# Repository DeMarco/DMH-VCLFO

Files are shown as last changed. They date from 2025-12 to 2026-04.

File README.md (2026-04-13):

# DMH-VCLFO
Kosmo format Voltage Controlled tripple LFO module

## Features
6 waveforms, all +5V/-5V
  - Square
  - Saw
  - Ramp
  - Random
  - Sine
  - Triangle

3 frequency ranges
  - Fast
  - Super Fast (Audio rate!)
  - Slow

Hard Sync input

Can also do VCO duties!

Excellent V/Oct trackig over 5 octaves

CV Amount knob serves as Fine Frequency Adjustment when no cable is connected to CV input

Adjustable range for Fine knob

## Current consumption:
+12V --> 65mA

-12V --> 60mA

## Dimensions
Height: 20cm

Width: 10cm

Depth: 10cm

## PCB set
- Panel
- Controls
- Main
- Submodule (x3)

Final Gerbers available in "Gerbers" folder

## Single VCLFO version
The KiCad project named "Single Unit" contains the circuit for one VCLFO in a single page schematic without any inter-PCB connectors. This can be useful if anyone is interested in designing their own PCBs or entire modules in non-Kosmo dimensions.

## Font
For viewing/customizing in KiCad, I recommend downloading and installing the Nulshock font from Typodermic: https://typodermicfonts.com/nulshock/




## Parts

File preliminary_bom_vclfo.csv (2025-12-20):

Reference | Value | Datasheet | Footprint | Qty | DNP
C1,C2 | 47uF | ~ | Capacitor_THT:CP_Radial_D5.0mm_P2.00mm | 2
C3 | 10nF | ~ | Capacitor_THT:C_Disc_D4.3mm_W1.9mm_P5.00mm | 1
C4,C6 | 1uF | ~ | Capacitor_THT:C_Disc_D4.3mm_W1.9mm_P5.00mm | 2
C5 | 1nF | ~ | Capacitor_THT:C_Disc_D4.3mm_W1.9mm_P5.00mm | 1
C7,C8 | 100nF | ~ | Capacitor_THT:C_Disc_D4.3mm_W1.9mm_P5.00mm | 2
C9,C10,C11 | 100pF | ~ | Capacitor_THT:C_Disc_D4.3mm_W1.9mm_P5.00mm | 3
D1,D2 | SB140 | http://www.diodes.com/_files/datasheets/ds23022.pdf | Diode_THT:D_DO-41_SOD81_P10.16mm_Horizontal | 2
D3,D4 | LM4040LP-5 | http://www.ti.com/lit/ds/symlink/lm4040-n.pdf | Package_TO_SOT_THT:TO-92_Inline | 2
D5 | LED_Red | ~ | LED_THT:LED_D3.0mm | 1
D6 | LED_Yellow | ~ | LED_THT:LED_D3.0mm | 1
D7,D8,D9,D10,D11,D12,D13,D14,D15,D16,D17 | 1N4148 | https://assets.nexperia.com/documents/data-sheet/1N4148_1N4448.pdf,~ | Diode_THT:D_DO-35_SOD27_P7.62mm_Horizontal | 11
J1,J2,J3,J4,J5,J6 | TS_Jack_6.35mm_Sw | ~ | SynthStuff:CUI_MJ-63052A | 6
J10 | IDC_02x05 | ~ | SynthStuff:IDC-Header_2x05_P2.54mm_Vertical_BackBone | 1
J100 | IDC_02x05 | ~ | SynthStuff:IDC-Header_2x05_P2.54mm_Vertical_Eurorack | 1
Q1,Q3,Q7 | BC548 | https://www.onsemi.com/pub/Collateral/BC550-D.pdf | Package_TO_SOT_THT:TO-92L_Inline_Wide | 3
Q2 | BC558 | https://www.onsemi.com/pub/Collateral/BC556BTA-D.pdf | Package_TO_SOT_THT:TO-92L_Inline_Wide | 1
Q4 | BC548 | https://www.onsemi.com/pub/Collateral/BC550-D.pdf | Package_TO_SOT_THT:TO-92_Inline_Wide | 1
Q5 | BS170 | https://www.onsemi.com/pub/Collateral/BS170-D.PDF | Package_TO_SOT_THT:TO-92_Inline | 1
Q6 | J113 | https://www.onsemi.com/pub/Collateral/MMBFJ113-D.PDF | Package_TO_SOT_THT:TO-92L_Inline | 1
R1,R2 | 6k8 | ~ | Resistor_THT:R_Axial_DIN0207_L6.3mm_D2.5mm_P7.62mm_Horizontal | 2
R3 | 270R | ~ | Resistor_THT:R_Axial_DIN0207_L6.3mm_D2.5mm_P7.62mm_Horizontal | 1
R4,R57 | 33k | ~ | Resistor_THT:R_Axial_DIN0207_L6.3mm_D2.5mm_P7.62mm_Horizontal | 2
R5,R6,R7,R8,R9,R10,R11,R12,R13,R14,R15,R16,R17,R18,R19,R20,R21,R22,R23,R24,R25,R26,R27,R28,R37,R38,R39,R40,R43,R45,R47,R50,R55,R58,R60,R64,R65,R68,R72,R73,R78,R79,R82,R86 | 100k | ~ | Resistor_THT:R_Axial_DIN0207_L6.3mm_D2.5mm_P7.62mm_Horizontal | 44
R29,R30,R31,R32,R33,R34,R44,R63,R70,R83 | 1k | ~ | Resistor_THT:R_Axial_DIN0207_L6.3mm_D2.5mm_P7.62mm_Horizontal | 10
R35,R36,R51,R53,R56,R59,R74,R75,R77,R80 | 10k | ~ | Resistor_THT:R_Axial_DIN0207_L6.3mm_D2.5mm_P7.62mm_Horizontal | 10
R41,R42 | 3k3 | ~ | Resistor_THT:R_Axial_DIN0207_L6.3mm_D2.5mm_P7.62mm_Horizontal | 2
R46,R48,R49 | 51k | ~ | Resistor_THT:R_Axial_DIN0207_L6.3mm_D2.5mm_P7.62mm_Horizontal | 3
R52 | 3k9 | ~ | Resistor_THT:R_Axial_DIN0207_L6.3mm_D2.5mm_P7.62mm_Horizontal | 1
R54 | 330R | ~ | Resistor_THT:R_Axial_DIN0207_L6.3mm_D2.5mm_P7.62mm_Horizontal | 1
R61,R81 | 1M | ~ | Resistor_THT:R_Axial_DIN0207_L6.3mm_D2.5mm_P7.62mm_Horizontal | 2
R62 | 47k | ~ | Resistor_THT:R_Axial_DIN0207_L6.3mm_D2.5mm_P7.62mm_Horizontal | 1
R66,R67,R85 | 22k | ~ | Resistor_THT:R_Axial_DIN0207_L6.3mm_D2.5mm_P7.62mm_Horizontal | 3
R69,R71 | 560 | ~ | Resistor_THT:R_Axial_DIN0207_L6.3mm_D2.5mm_P7.62mm_Horizontal | 2
R76 | 82k | ~ | Resistor_THT:R_Axial_DIN0207_L6.3mm_D2.5mm_P7.62mm_Horizontal | 1
RV1,RV2 | B100k | ~ | SynthStuff:Potentiometer_TT_P110KH1 | 2
RV3 | 50k | ~ | Potentiometer_THT:Potentiometer_Bourns_3296X_Horizontal | 1
RV4 | 10k | ~ | Potentiometer_THT:Potentiometer_Bourns_3296W_Vertical | 1
SW1,SW3,SW4 | SW_SPDT | ~ | SynthStuff:Toggle_Switch_TE | 3
SW2 | SPDT_OnOffOn | ~ | SynthStuff:Toggle_Switch_TE | 1
U1,U2,U10,U11,U12 | TL074 | http://www.ti.com/lit/ds/symlink/tl071.pdf | Package_DIP:DIP-14_W7.62mm_Socket | 5

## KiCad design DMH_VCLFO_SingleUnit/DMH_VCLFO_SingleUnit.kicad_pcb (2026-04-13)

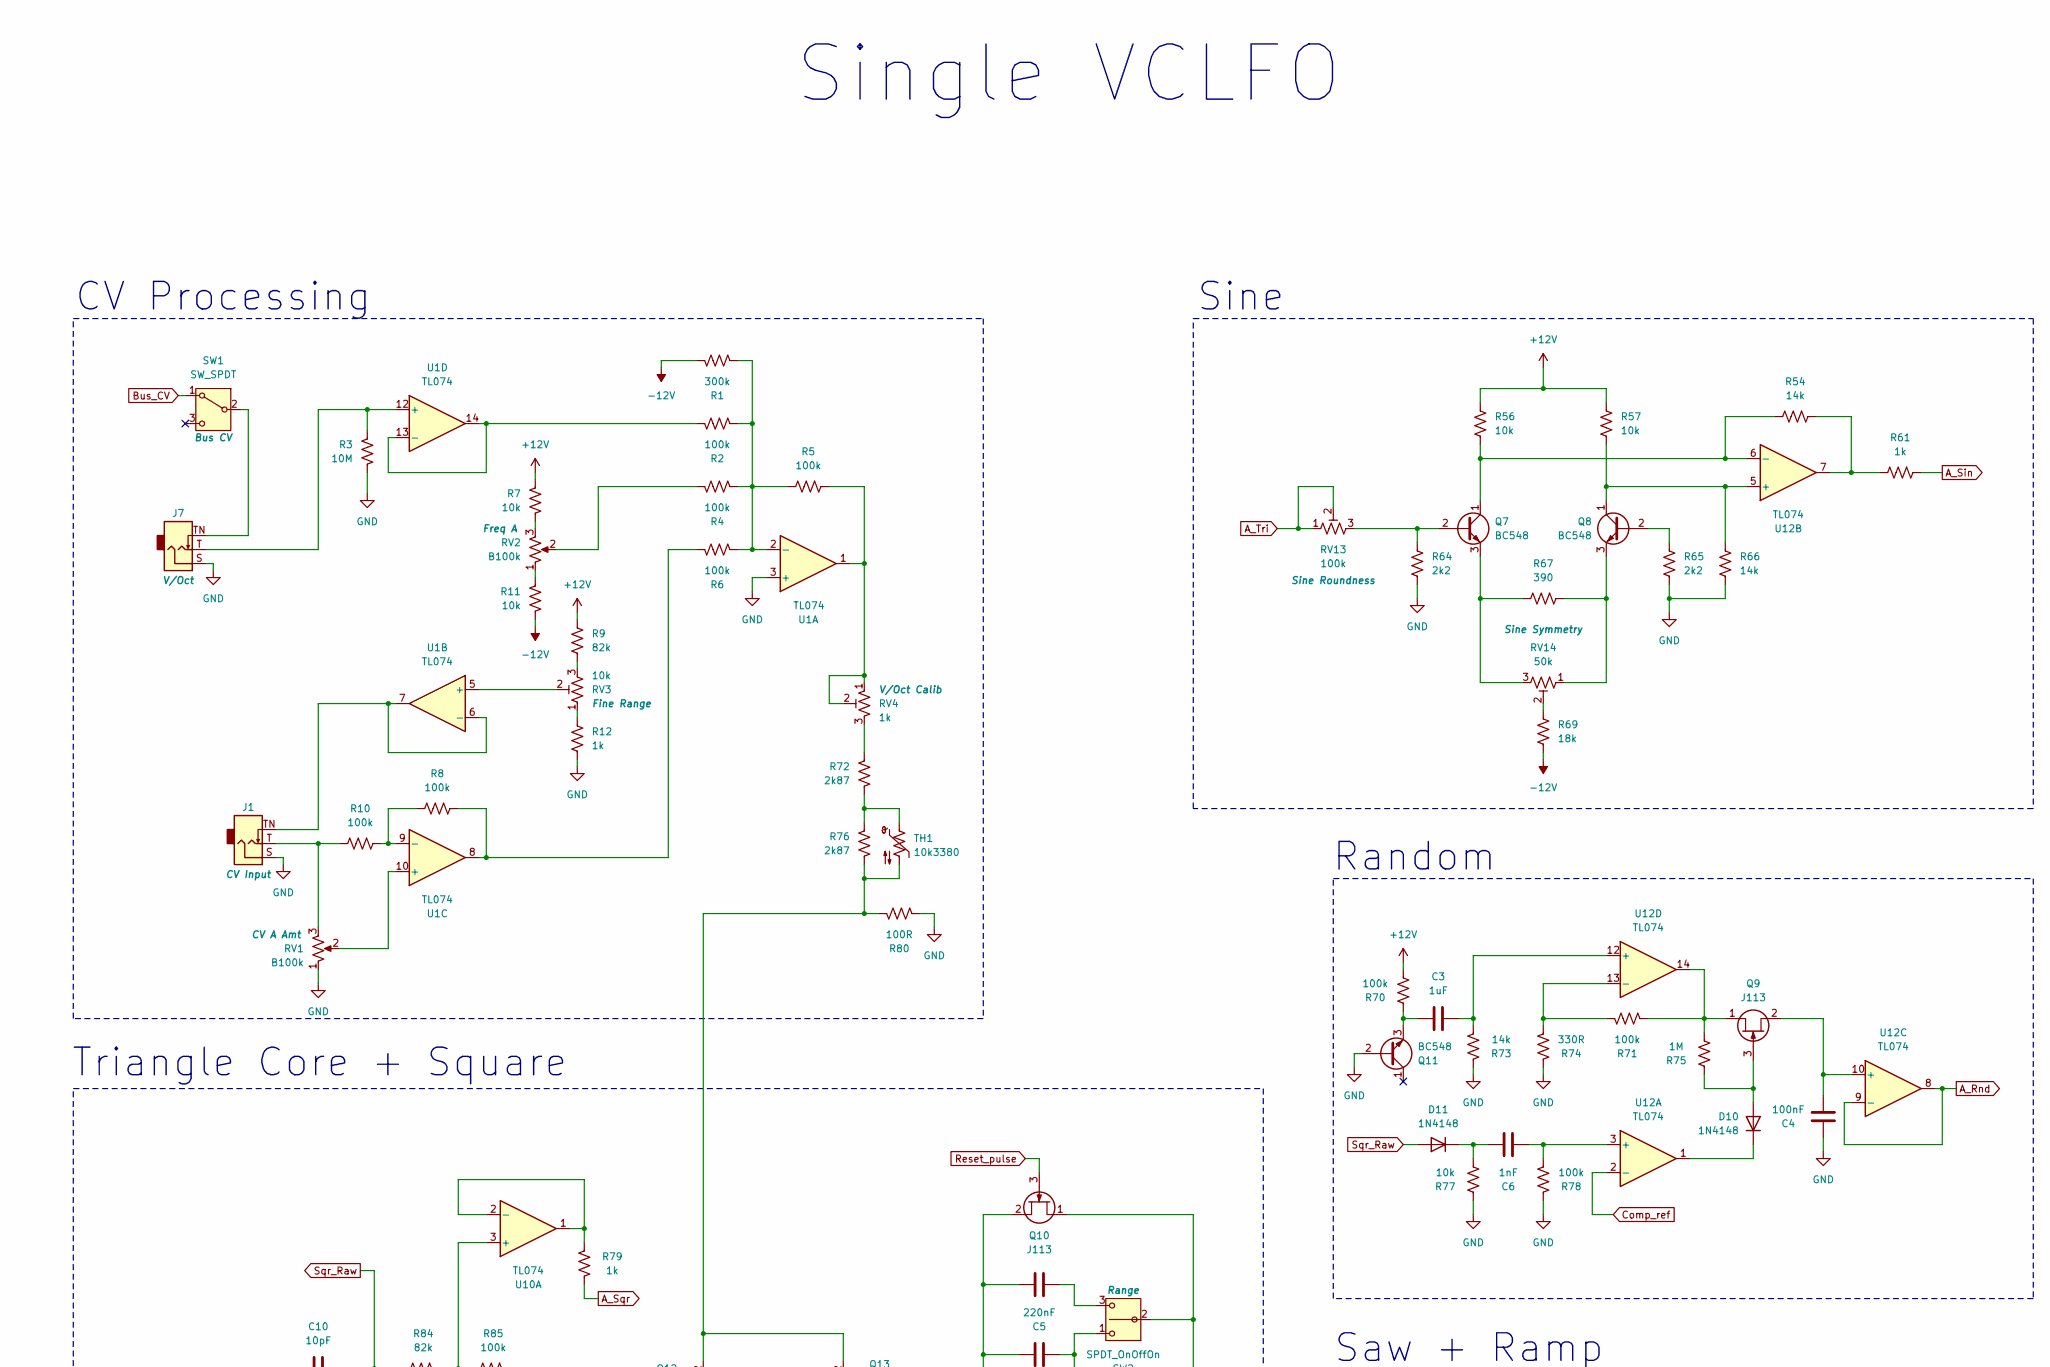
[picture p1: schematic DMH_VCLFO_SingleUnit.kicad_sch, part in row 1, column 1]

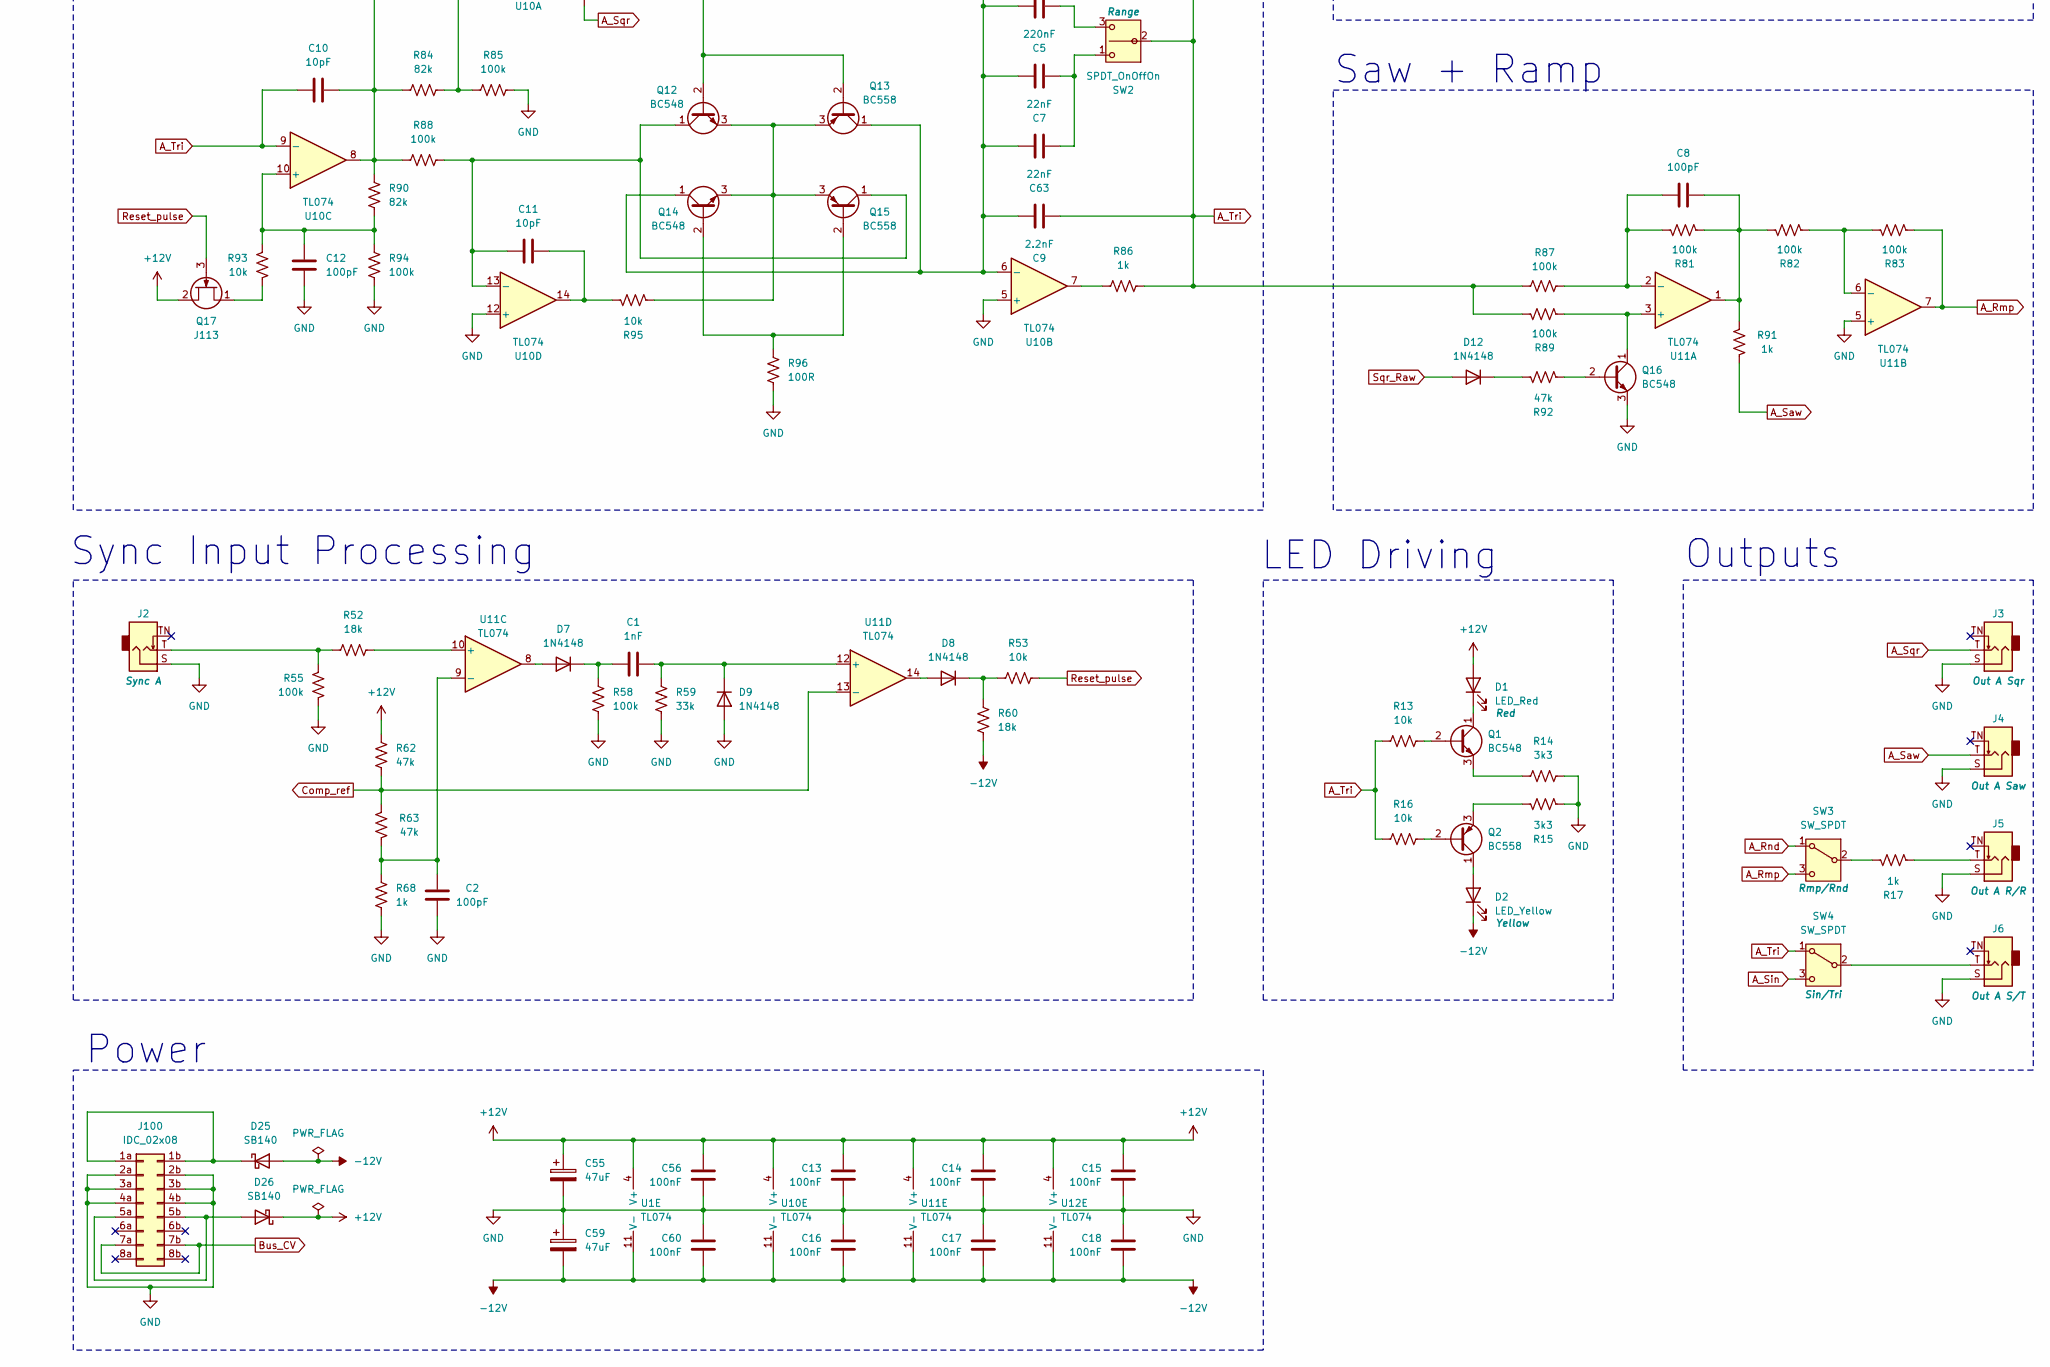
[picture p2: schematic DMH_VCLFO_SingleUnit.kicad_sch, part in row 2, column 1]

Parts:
C1, C6: 1nF; C_Disc_D4.3mm_W1.9mm_P5.00mm
C2, C8, C12: 100pF; C_Disc_D3.0mm_W2.0mm_P2.50mm
C3: 1uF; C_Disc_D4.3mm_W1.9mm_P5.00mm
C4, C13, C14, C15, C16, C17, C18, C56, C60: 100nF; C_Disc_D4.3mm_W1.9mm_P5.00mm
C5: 220nF; C_Disc_D4.3mm_W1.9mm_P5.00mm
C7, C63: 22nF; C_Disc_D4.3mm_W1.9mm_P5.00mm
C9: 2.2nF; C_Disc_D3.0mm_W2.0mm_P2.50mm
C10, C11: 10pF; C_Disc_D3.0mm_W2.0mm_P2.50mm
C55, C59: 47uF; CP_Radial_D5.0mm_P2.00mm
D1: LED_Red; LED_D3.0mm
D2: LED_Yellow; LED_D3.0mm
D7, D8, D9, D10, D11, D12: 1N4148; D_DO-35_SOD27_P7.62mm_Horizontal
D25, D26: SB140; D_DO-41_SOD81_P10.16mm_Horizontal
J1, J2, J3, J4, J5, J6, J7: TS_Jack_6.35mm_Sw; CUI_MJ-63052A
J100: IDC_02x08; IDC-Header_2x08_P2.54mm_Vertical_Eurorack
Q1, Q7, Q8, Q11, Q12, Q14, Q16: BC548; TO-92L_Inline_Wide
Q2, Q13, Q15: BC558; TO-92L_Inline_Wide
Q9, Q10, Q17: J113; TO-92L_Inline
R1: 300k; R_Axial_DIN0207_L6.3mm_D2.5mm_P7.62mm_Horizontal
R2, R4, R5, R6, R8, R10, R55, R58, R70, R71, R78, R81, R82, R83, R85, R87, R88, R89, R94: 100k; R_Axial_DIN0207_L6.3mm_D2.5mm_P7.62mm_Horizontal
R3: 10M; R_Axial_DIN0207_L6.3mm_D2.5mm_P7.62mm_Horizontal
R7, R11, R13, R16, R53, R56, R57, R77, R93, R95: 10k; R_Axial_DIN0207_L6.3mm_D2.5mm_P7.62mm_Horizontal
R9, R84, R90: 82k; R_Axial_DIN0207_L6.3mm_D2.5mm_P7.62mm_Horizontal
R12, R17, R61, R68, R79, R86, R91: 1k; R_Axial_DIN0207_L6.3mm_D2.5mm_P7.62mm_Horizontal
R14, R15: 3k3; R_Axial_DIN0207_L6.3mm_D2.5mm_P7.62mm_Horizontal
R52, R60, R69: 18k; R_Axial_DIN0207_L6.3mm_D2.5mm_P7.62mm_Horizontal
R54, R66, R73: 14k; R_Axial_DIN0207_L6.3mm_D2.5mm_P7.62mm_Horizontal
R59: 33k; R_Axial_DIN0207_L6.3mm_D2.5mm_P7.62mm_Horizontal
R62, R63, R92: 47k; R_Axial_DIN0207_L6.3mm_D2.5mm_P7.62mm_Horizontal
R64, R65: 2k2; R_Axial_DIN0207_L6.3mm_D2.5mm_P7.62mm_Horizontal
R67: 390; R_Axial_DIN0207_L6.3mm_D2.5mm_P7.62mm_Horizontal
R72, R76: 2k87; R_Axial_DIN0207_L6.3mm_D2.5mm_P7.62mm_Horizontal
R74: 330R; R_Axial_DIN0207_L6.3mm_D2.5mm_P7.62mm_Horizontal
R75: 1M; R_Axial_DIN0207_L6.3mm_D2.5mm_P7.62mm_Horizontal
R80, R96: 100R; R_Axial_DIN0207_L6.3mm_D2.5mm_P7.62mm_Horizontal
RV1, RV2: B100k; Potentiometer_Alpha_RD901F-40-00D_Single_Vertical
RV3: 10k; Potentiometer_Bourns_3296W_Vertical
RV4: 1k; Potentiometer_Bourns_3296W_Vertical
RV13: 100k; Potentiometer_Bourns_3296W_Vertical
RV14: 50k; Potentiometer_Bourns_3296W_Vertical
SW1, SW3, SW4: SW_SPDT; Toggle_Switch_TE
SW2: SPDT_OnOffOn; Toggle_Switch_TE
TH1: 10k3380; R_Axial_DIN0204_L3.6mm_D1.6mm_P1.90mm_Vertical
U1, U10, U11, U12: TL074; DIP-14_W7.62mm_Socket

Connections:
+12V: C13.1, C14.1, C15.1, C55.1, C56.1, D1.2 (A), D26.1 (K), Q17.2 (S), R7.1, R9.2, R56.1, R57.1, R62.1, R70.1, U1.4 (V+), U10.4 (V+), U11.4 (V+), U12.4 (V+)
-12V: C16.2, C17.2, C18.2, C59.2, C60.2, D2.1 (K), D25.2 (A), R1.1, R11.2, R60.2, R69.1, U1.11 (V-), U10.11 (V-), U11.11 (V-), U12.11 (V-)
A_Rmp: R83.2, SW3.3 (C), U11.7
A_Rnd: SW3.1 (A), U12.8, U12.9 (-)
A_Saw: J4.T, R91.1
A_Sin: R61.2, SW4.3 (C)
A_Sqr: J3.T, R79.1
A_Tri: C9.2, C10.1, Q10.1 (D), R13.1, R16.1, R86.1, R87.1, R89.1, RV13.1, RV13.2, SW2.2 (B), SW4.1 (A), U10.9 (-)
Bus_CV: J100.7a, J100.7b, SW1.1 (A)
Comp_ref: R62.2, R63.1, U11.13 (-), U12.2 (-)
GND: C2.1, C4.2, C12.1, C13.2, C14.2, C15.2, C16.1, C17.1, C18.1, C55.2, C56.2, C59.1, C60.1, D9.2 (A), J1.S, J2.S, J3.S, J4.S, J5.S, J6.S, J7.S, J100.2a, J100.2b, J100.3a, J100.3b, J100.4a, J100.4b, Q11.2 (B), Q16.3 (E), R3.2, R12.1, R14.2, R15.2, R55.1, R58.2, R59.2, R64.2, R65.2, R66.2, R68.2, R73.2, R74.2, R77.2, R78.2, R80.1, R85.1, R94.2, R96.2, RV1.1, U1.3 (+), U10.5 (+), U10.12 (+), U11.5 (+)
unnamed: C8.2, R81.2, R82.1, R91.2, U11.1
unnamed: C11.2, R95.2, U10.14
unnamed: D1.1 (K), Q1.1 (C)
unnamed: D2.2 (A), Q2.1 (C)
unnamed: D7.2 (A), U11.8
unnamed: C1.1, D7.1 (K), R58.1
unnamed: D8.2 (A), U11.14
unnamed: D8.1 (K), R53.2, R60.1
unnamed: C1.2, D9.1 (K), R59.1, U11.12 (+)
unnamed: D10.2 (A), Q9.3 (G), R75.2
unnamed: D10.1 (K), U12.1
unnamed: C6.2, D11.1 (K), R77.1
unnamed: D12.1 (K), R92.1
unnamed: D25.1 (K), J100.1a, J100.1b
unnamed: D26.2 (A), J100.5a, J100.5b
unnamed: J1.T, R10.1, RV1.3
unnamed: J2.T, R52.1, R55.2
unnamed: J5.T, R17.2
unnamed: Q1.2 (B), R13.2
unnamed: Q1.3 (E), R14.1
unnamed: Q2.2 (B), R16.2
unnamed: Q2.3 (E), R15.1
unnamed: Q7.2 (B), R64.1, RV13.3
unnamed: Q7.1 (C), R54.1, R56.2, U12.6 (-)
unnamed: Q7.3 (E), R67.1, RV14.3
unnamed: Q8.2 (B), R65.1
unnamed: Q8.1 (C), R57.2, R66.1, U12.5 (+)
unnamed: Q8.3 (E), R67.2, RV14.1
unnamed: Q9.1 (D), R71.1, R75.1, U12.14
unnamed: C4.1, Q9.2 (S), U12.10 (+)
unnamed: C5.1, C7.1, C9.1, C63.1, Q10.2 (S), Q13.1 (C), Q14.1 (C), U10.6 (-)
unnamed: C3.1, Q11.3 (E), R70.2
unnamed: Q12.2 (B), Q13.2 (B), R76.2, R80.2, TH1.2
unnamed: C11.1, Q12.1 (C), Q15.1 (C), R88.1, U10.13 (-)
unnamed: Q12.3 (E), Q13.3 (E), Q14.3 (E), Q15.3 (E), R95.1
unnamed: Q14.2 (B), Q15.2 (B), R96.1
unnamed: Q16.2 (B), R92.2
unnamed: Q16.1 (C), R89.2, U11.3 (+)
unnamed: Q17.1 (D), R93.2
unnamed: R4.2, RV2.2
unnamed: R5.2, RV4.1, RV4.2, U1.1
unnamed: R6.2, R8.2, U1.8
unnamed: R7.2, RV2.3
unnamed: R9.1, RV3.3
unnamed: R11.1, RV2.1
unnamed: R12.2, RV3.1
unnamed: R54.2, R61.1, U12.7
unnamed: R69.2, RV14.2
unnamed: R72.1, RV4.3
unnamed: R72.2, R76.1, TH1.1
unnamed: R86.2, U10.7
unnamed: J7.TN, SW1.2 (B)
unnamed: C7.2, C63.2, SW2.1 (A)
unnamed: C5.2, SW2.3 (C)
unnamed: R17.1, SW3.2 (B)
unnamed: J6.T, SW4.2 (B)
unnamed: R1.2, R2.1, R4.1, R5.1, R6.1, U1.2 (-)
unnamed: RV3.2, U1.5 (+)
unnamed: J1.TN, U1.6 (-), U1.7
unnamed: RV1.2, U1.10 (+)
unnamed: R8.1, R10.2, U1.9 (-)
unnamed: J7.T, R3.1, U1.12 (+)
unnamed: R2.2, U1.13 (-), U1.14
unnamed: R84.1, R85.2, U10.3 (+)
unnamed: R79.2, U10.1, U10.2 (-)
unnamed: C12.2, R90.2, R93.1, R94.1, U10.10 (+)
unnamed: C8.1, R81.1, R87.2, U11.2 (-)
unnamed: R82.2, R83.1, U11.6 (-)
unnamed: R52.2, U11.10 (+)
unnamed: C2.2, R63.2, R68.1, U11.9 (-)
unnamed: C6.1, R78.1, U12.3 (+)
unnamed: C3.2, R73.1, U12.12 (+)
unnamed: R71.2, R74.1, U12.13 (-)
Reset_pulse: Q10.3 (G), Q17.3 (G), R53.1
Sqr_Raw: C10.2, D11.2 (A), D12.2 (A), R84.2, R88.2, R90.1, U10.8

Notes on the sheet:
Random
Triangle Core + Square
Sine
CV Processing
Single VCLFO
Outputs
Power
Saw + Ramp
LED Driving
Sync Input Processing

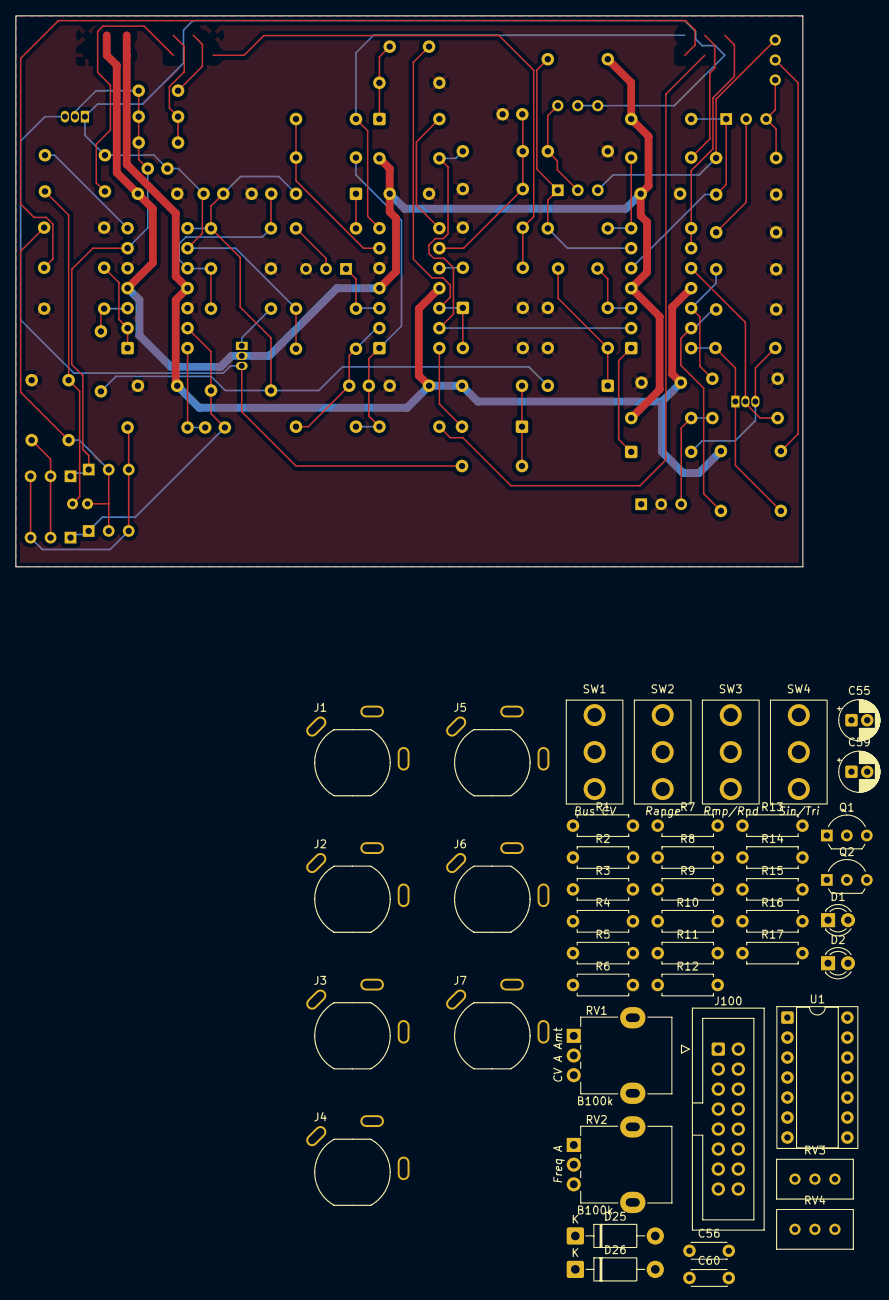
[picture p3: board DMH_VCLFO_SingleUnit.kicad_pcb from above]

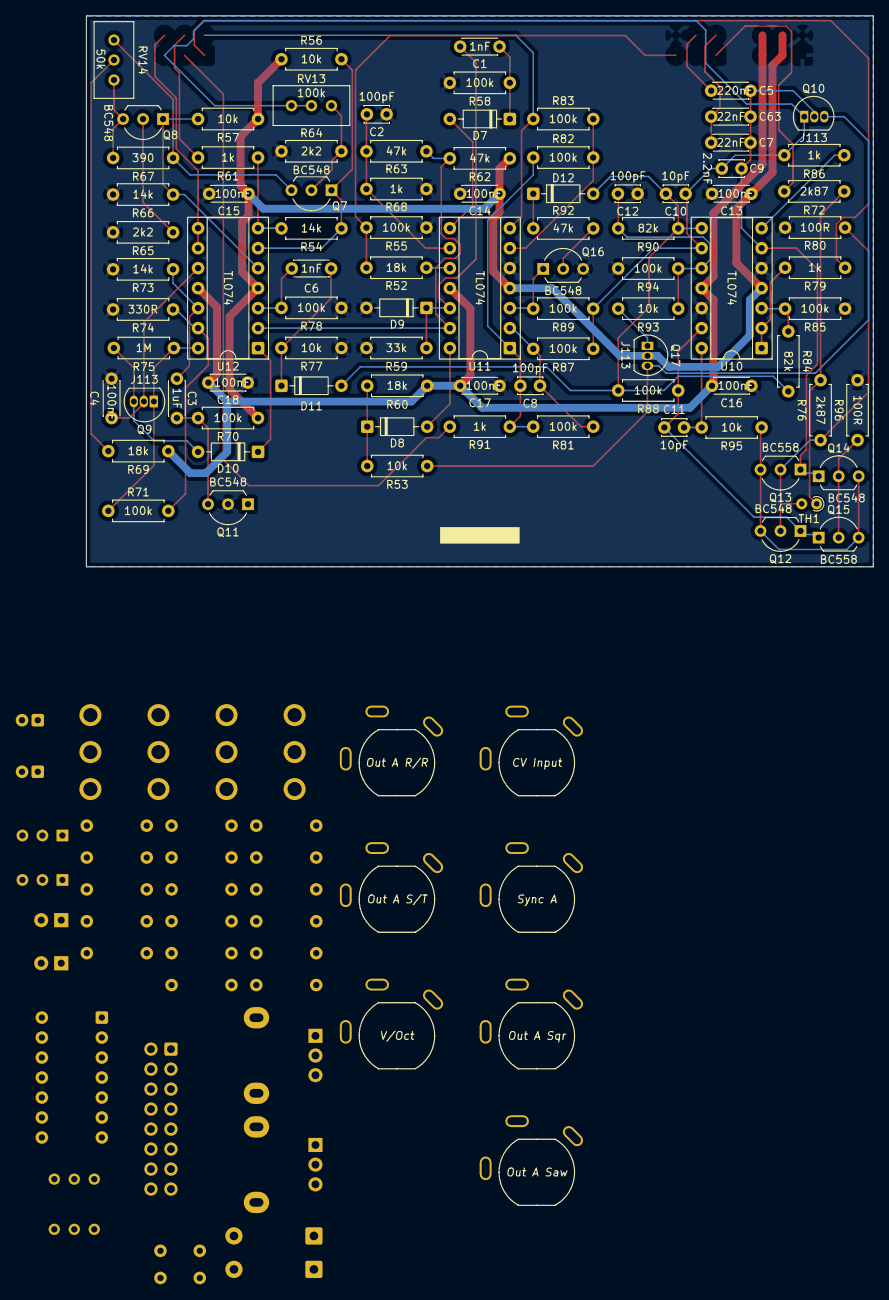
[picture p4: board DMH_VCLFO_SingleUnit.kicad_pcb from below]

Board: 2 copper layers, 100.0 x 70.0 mm, 131 parts (87 on the bottom side), 86 nets.

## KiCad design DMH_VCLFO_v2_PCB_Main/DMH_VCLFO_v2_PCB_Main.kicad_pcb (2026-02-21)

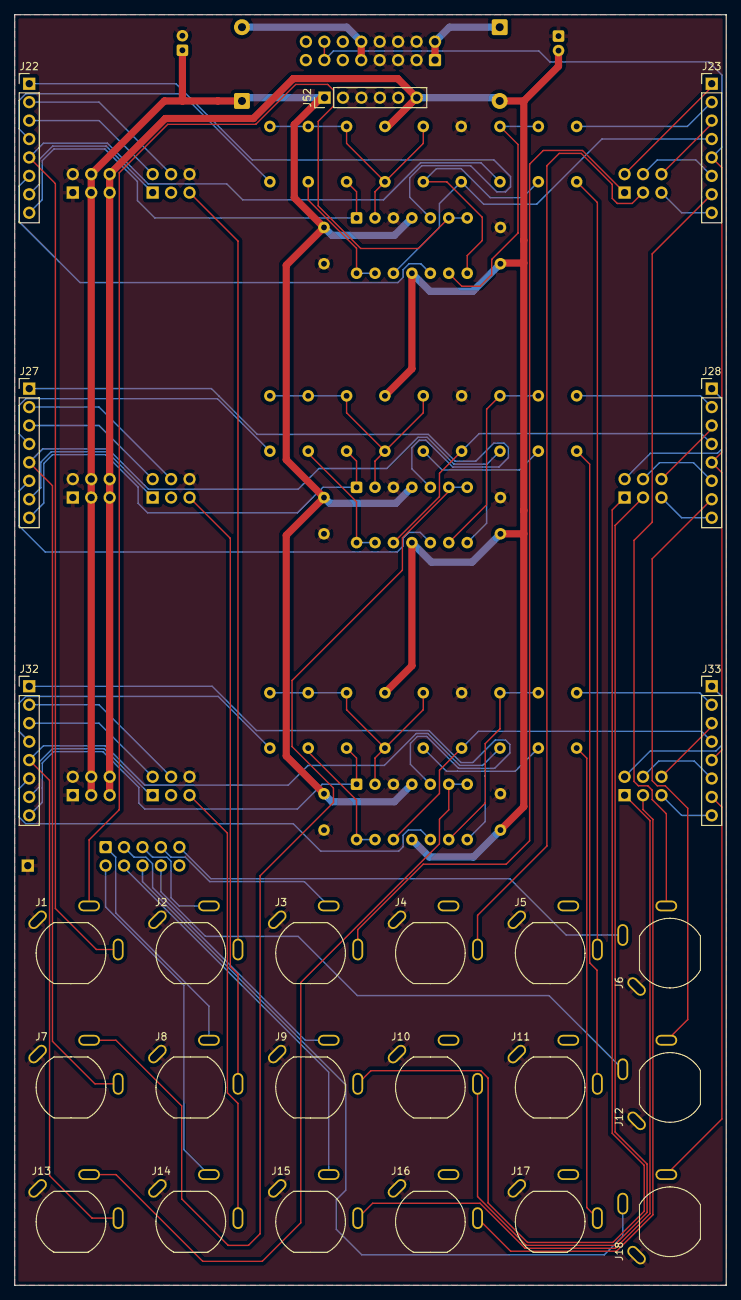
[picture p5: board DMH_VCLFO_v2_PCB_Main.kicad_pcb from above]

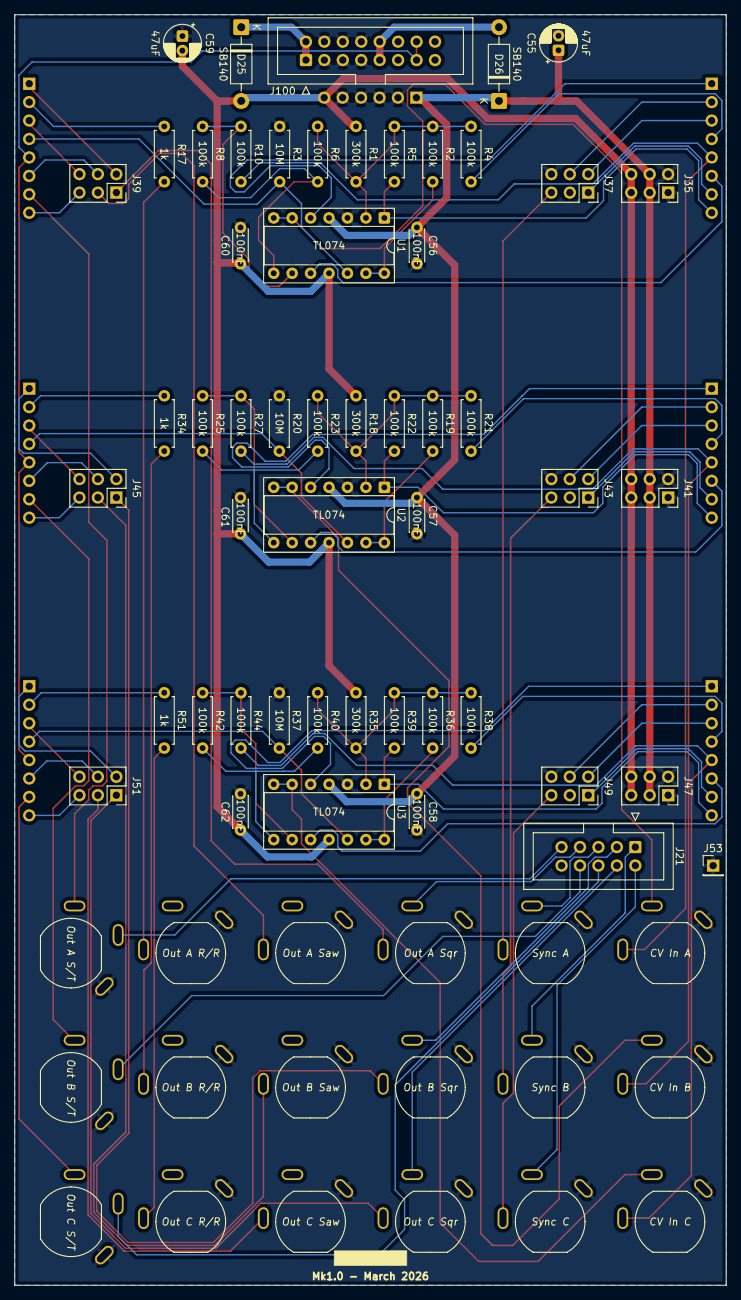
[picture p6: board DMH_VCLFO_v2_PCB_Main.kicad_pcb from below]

Board: 2 copper layers, 98.0 x 175.0 mm, 77 parts (52 on the bottom side), 87 nets.

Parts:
C55, C59: 47uF; CP_Radial_D5.0mm_P2.00mm
C56, C57, C58, C60, C61, C62: 100nF; C_Disc_D4.3mm_W1.9mm_P5.00mm
D25, D26: SB140; D_DO-41_SOD81_P10.16mm_Horizontal
J1, J2, J3, J4, J5, J6, J7, J8, J9, J10, J11, J12, J13, J14, J15, J16, J17, J18: TS_Jack_6.35mm_Sw; CUI_MJ-63052A
J21: IDC_02x05; IDC-Header_2x05_P2.54mm_Vertical_BackBone
J22, J23, J27, J28, J32, J33: Conn_01x08; PinHeader_1x08_P2.54mm_Vertical
J35, J37, J39, J41, J43, J45, J47, J49, J51: Conn_02x03_Odd_Even; PinSocket_2x03_P2.54mm_Vertical
J52: Conn_01x06; PinHeader_1x06_P2.54mm_Vertical
J53: Conn_01x01; PinHeader_1x01_P2.54mm_Vertical
J100: IDC_02x08; IDC-Header_2x08_P2.54mm_Vertical_Eurorack
R1, R18, R35: 300k; R_Axial_DIN0207_L6.3mm_D2.5mm_P7.62mm_Horizontal
R2, R4, R5, R6, R8, R10, R19, R21, R22, R23, R25, R27, R36, R38, R39, R40, R42, R44: 100k; R_Axial_DIN0207_L6.3mm_D2.5mm_P7.62mm_Horizontal
R3, R20, R37: 10M; R_Axial_DIN0207_L6.3mm_D2.5mm_P7.62mm_Horizontal
R17, R34, R51: 1k; R_Axial_DIN0207_L6.3mm_D2.5mm_P7.62mm_Horizontal
U1, U2, U3: TL074; DIP-14_W7.62mm_Socket

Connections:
+12V: C55.1, C56.1, C57.1, C58.1, D26.1 (K), J35.3, J35.4, J41.3, J41.4, J47.3, J47.4, J52.1, U1.4 (V+), U2.4 (V+), U3.4 (V+)
-12V: C59.2, C60.2, C61.2, C62.2, D25.2 (A), J35.5, J35.6, J41.5, J41.6, J47.5, J47.6, J52.6, R1.1, R18.1, R35.1, U1.11 (V-), U2.11 (V-), U3.11 (V-)
A_BusCV_Sw_p2_M: J23.4, R3.1, U1.12 (+)
A_CV_Amt_Pot_p2_M: J22.6, U1.10 (+)
A_CV_Amt_Pot_p3_M: J1.T, J22.5, R10.1
A_FRng_Trim_p2_M: J22.1, U1.5 (+)
A_Freq_Pot_p2_M: J22.4, R4.2
A_Out_Sin_Tri_TN_M: J6.TN, J21.5
A_Out_Sqr_TN_M: J3.TN, J21.4
A_Rmp_M: J23.1, J39.2
A_Rmp_Rnd_Sw_p2_M: J23.2, R17.1
A_Rnd_M: J23.3, J39.6
A_Rng_Sw_p1_M: J22.3, J37.2
A_Rng_Sw_p3_M: J22.2, J37.4
A_Saw_M: J4.T, J39.3
A_Sin_M: J23.6, J39.4
A_Sin_Tri_Sw_p2_M: J6.T, J23.7
A_Sqr_M: J3.T, J39.1
A_Sync_M: J2.T, J37.5
A_Sync_TN_M: J2.TN, J21.3
A_Tri_M: J23.8, J39.5
A_VOct_Trim_p3_M: J22.7, J37.1
A_VOct_Trim_p12_M: J22.8, R5.2, U1.1
B_BusCV_Sw_p2_M: J28.4, R20.1, U2.12 (+)
B_CV_Amt_Pot_p2_M: J27.6, U2.10 (+)
B_CV_Amt_Pot_p3_M: J7.T, J27.5, R27.1
B_FRng_Trim_p2_M: J27.1, U2.5 (+)
B_Freq_Pot_p2_M: J27.4, R21.2
B_Out_Sin_Tri_TN_M: J12.TN, J21.9
B_Out_Sqr_TN_M: J9.TN, J21.2
B_Rmp_M: J28.1, J45.2
B_Rmp_Rnd_Sw_p2_M: J28.2, R34.1
B_Rnd_M: J28.3, J45.6
B_Rng_Sw_p1_M: J27.3, J43.2
B_Rng_Sw_p3_M: J27.2, J43.4
B_Saw_M: J10.T, J45.3
B_Sin_M: J28.6, J45.4
B_Sin_Tri_Sw_p2_M: J12.T, J28.7
B_Sqr_M: J9.T, J45.1
B_Sync_M: J8.T, J43.5
B_Sync_TN_M: J8.TN, J21.1
B_Tri_M: J28.8, J45.5
B_VOct_Trim_p3_M: J27.7, J43.1
B_VOct_Trim_p12_M: J27.8, R22.2, U2.1
Bus_CV_M: J23.5, J28.5, J33.5, J100.7a, J100.7b
C_BusCV_Sw_p2_M: J33.4, R37.1, U3.12 (+)
C_CV_Amt_Pot_p2_M: J32.6, U3.10 (+)
C_CV_Amt_Pot_p3_M: J13.T, J32.5, R44.1
C_FRng_Trim_p2_M: J32.1, U3.5 (+)
C_Freq_Pot_p2_M: J32.4, R38.2
C_Out_Sin_Tri_TN_M: J18.TN, J21.8
C_Out_Sqr_TN_M: J15.TN, J21.7
C_Rmp_M: J33.1, J51.2
C_Rmp_Rnd_Sw_p2_M: J33.2, R51.1
C_Rnd_M: J33.3, J51.6
C_Rng_Sw_p1_M: J32.3, J49.2
C_Rng_Sw_p3_M: J32.2, J49.4
C_Saw_M: J16.T, J51.3
C_Sin_M: J33.6, J51.4
C_Sin_Tri_Sw_p2_M: J18.T, J33.7
C_Sqr_M: J15.T, J51.1
C_Sync_M: J14.T, J49.5
C_Sync_TN_M: J14.TN, J21.6
C_Tri_M: J33.8, J51.5
C_VOct_Trim_p3_M: J32.7, J49.1
C_VOct_Trim_p12_M: J32.8, R39.2, U3.1
GND: C55.2, C56.2, C57.2, C58.2, C59.1, C60.1, C61.1, C62.1, J1.S, J2.S, J3.S, J4.S, J5.S, J6.S, J7.S, J8.S, J9.S, J10.S, J11.S, J12.S, J13.S, J14.S, J15.S, J16.S, J17.S, J18.S, J35.1, J35.2, J37.6, J41.1, J41.2, J43.6, J47.1, J47.2, J49.6, J52.2, J52.3, J52.4, J52.5, J53.1, J100.2a, J100.2b, J100.3a, J100.3b, J100.4a, J100.4b, R3.2, R20.2, R37.2, U1.3 (+), U2.3 (+), U3.3 (+)
unnamed: D25.1 (K), J100.1a, J100.1b
unnamed: D26.2 (A), J100.5a, J100.5b
unnamed: J5.T, R17.2
unnamed: J11.T, R34.2
unnamed: J17.T, R51.2
unnamed: R6.2, R8.2, U1.8
unnamed: R23.2, R25.2, U2.8
unnamed: R40.2, R42.2, U3.8
unnamed: R1.2, R2.1, R4.1, R5.1, R6.1, U1.2 (-)
unnamed: J1.TN, U1.6 (-), U1.7
unnamed: R8.1, R10.2, U1.9 (-)
unnamed: R2.2, U1.13 (-), U1.14
unnamed: R18.2, R19.1, R21.1, R22.1, R23.1, U2.2 (-)
unnamed: J7.TN, U2.6 (-), U2.7
unnamed: R25.1, R27.2, U2.9 (-)
unnamed: R19.2, U2.13 (-), U2.14
unnamed: R35.2, R36.1, R38.1, R39.1, R40.1, U3.2 (-)
unnamed: J13.TN, U3.6 (-), U3.7
unnamed: R42.1, R44.2, U3.9 (-)
unnamed: R36.2, U3.13 (-), U3.14

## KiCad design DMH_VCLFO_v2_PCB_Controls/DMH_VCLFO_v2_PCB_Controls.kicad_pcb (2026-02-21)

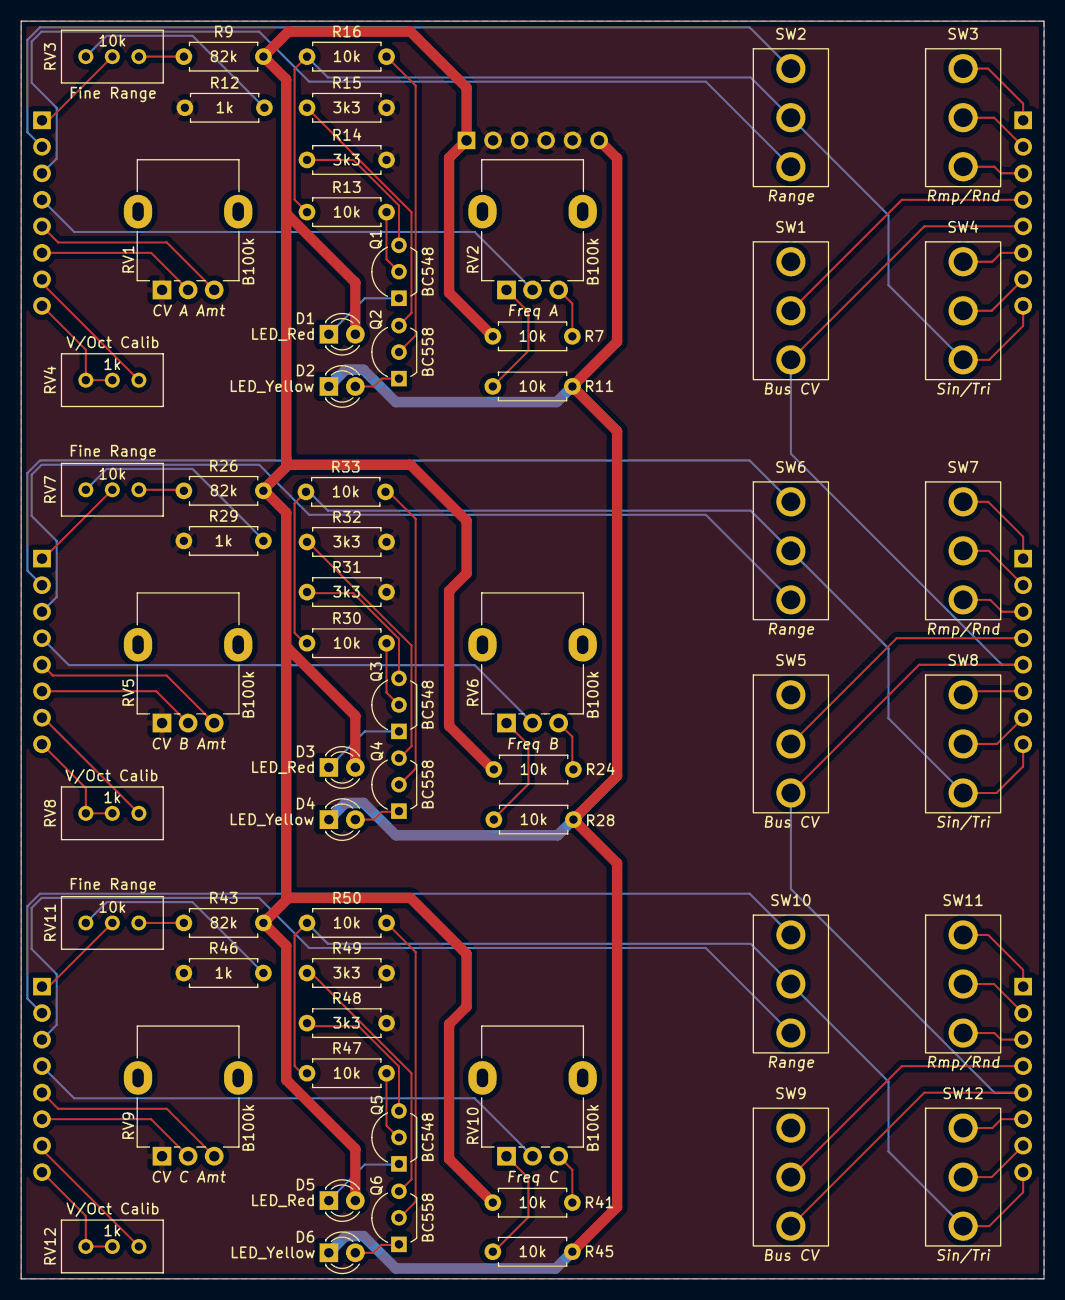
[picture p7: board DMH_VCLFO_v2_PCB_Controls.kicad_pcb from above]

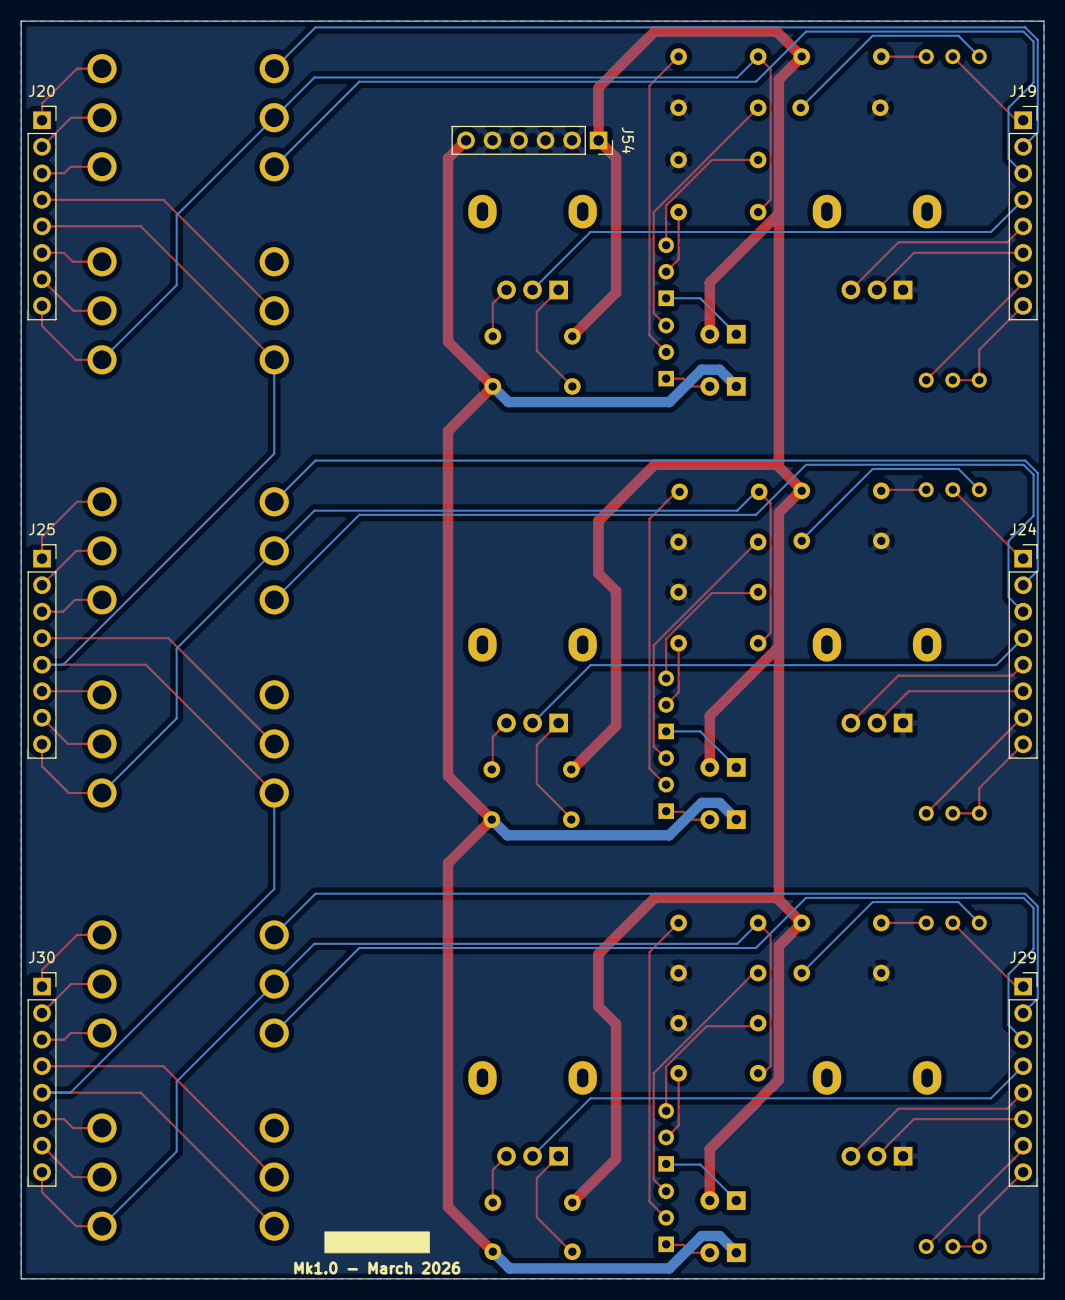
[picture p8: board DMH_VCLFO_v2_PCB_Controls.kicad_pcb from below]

Board: 2 copper layers, 98.0 x 120.5 mm, 67 parts (7 on the bottom side), 79 nets.

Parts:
D1, D3, D5: LED_Red; LED_D3.0mm
D2, D4, D6: LED_Yellow; LED_D3.0mm
J19, J20, J24, J25, J29, J30: Conn_01x08; PinSocket_1x08_P2.54mm_Vertical
J54: Conn_01x06; PinSocket_1x06_P2.54mm_Vertical
Q1, Q3, Q5: BC548; TO-92L_Inline_Wide
Q2, Q4, Q6: BC558; TO-92L_Inline_Wide
R7, R11, R13, R16, R24, R28, R30, R33, R41, R45, R47, R50: 10k; R_Axial_DIN0207_L6.3mm_D2.5mm_P7.62mm_Horizontal
R9, R26, R43: 82k; R_Axial_DIN0207_L6.3mm_D2.5mm_P7.62mm_Horizontal
R12, R29, R46: 1k; R_Axial_DIN0207_L6.3mm_D2.5mm_P7.62mm_Horizontal
R14, R15, R31, R32, R48, R49: 3k3; R_Axial_DIN0207_L6.3mm_D2.5mm_P7.62mm_Horizontal
RV1, RV2, RV5, RV6, RV9, RV10: B100k; Potentiometer_Alpha_RD901F-40-00D_Single_Vertical
RV3, RV7, RV11: 10k; Potentiometer_Bourns_3296W_Vertical
RV4, RV8, RV12: 1k; Potentiometer_Bourns_3296W_Vertical
SW1, SW3, SW4, SW5, SW7, SW8, SW9, SW11, SW12: SW_SPDT; Toggle_Switch_TE
SW2, SW6, SW10: SPDT_OnOffOn; Toggle_Switch_TE

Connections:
+12V: D1.2 (A), D3.2 (A), D5.2 (A), J54.1, R7.1, R9.2, R24.1, R26.2, R41.1, R43.2
-12V: D2.1 (K), D4.1 (K), D6.1 (K), J54.6, R11.2, R28.2, R45.2
A_BusCV_Sw_p2_C: J20.4, SW1.2 (B)
A_CV_Amt_Pot_p2_C: J19.6, RV1.2
A_CV_Amt_Pot_p3_C: J19.5, RV1.3
A_FRng_Trim_p2_C: J19.1, RV3.2
A_Freq_Pot_p2_C: J19.4, RV2.2
A_Rmp_C: J20.1, SW3.3 (C)
A_Rmp_Rnd_Sw_p2_C: J20.2, SW3.2 (B)
A_Rnd_C: J20.3, SW3.1 (A)
A_Rng_Sw_p1_C: J19.3, SW2.1 (A)
A_Rng_Sw_p3_C: J19.2, SW2.3 (C)
A_Sin_C: J20.6, SW4.3 (C)
A_Sin_Tri_Sw_p2_C: J20.7, SW4.2 (B)
A_Tri_C: J20.8, R13.1, R16.1, SW2.2 (B), SW4.1 (A)
A_VOct_Trim_p3_C: J19.7, RV4.3
A_VOct_Trim_p12_C: J19.8, RV4.1, RV4.2
B_BusCV_Sw_p2_C: J25.4, SW5.2 (B)
B_CV_Amt_Pot_p2_C: J24.6, RV5.2
B_CV_Amt_Pot_p3_C: J24.5, RV5.3
B_FRng_Trim_p2_C: J24.1, RV7.2
B_Freq_Pot_p2_C: J24.4, RV6.2
B_Rmp_C: J25.1, SW7.3 (C)
B_Rmp_Rnd_Sw_p2_C: J25.2, SW7.2 (B)
B_Rnd_C: J25.3, SW7.1 (A)
B_Rng_Sw_p1_C: J24.3, SW6.1 (A)
B_Rng_Sw_p3_C: J24.2, SW6.3 (C)
B_Sin_C: J25.6, SW8.3 (C)
B_Sin_Tri_Sw_p2_C: J25.7, SW8.2 (B)
B_Tri_C: J25.8, R30.1, R33.1, SW6.2 (B), SW8.1 (A)
B_VOct_Trim_p3_C: J24.7, RV8.3
B_VOct_Trim_p12_C: J24.8, RV8.1, RV8.2
Bus_CV_C: J20.5, J25.5, J30.5, SW1.1 (A), SW5.1 (A), SW9.1 (A)
C_BusCV_Sw_p2_C: J30.4, SW9.2 (B)
C_CV_Amt_Pot_p2_C: J29.6, RV9.2
C_CV_Amt_Pot_p3_C: J29.5, RV9.3
C_FRng_Trim_p2_C: J29.1, RV11.2
C_Freq_Pot_p2_C: J29.4, RV10.2
C_Rmp_C: J30.1, SW11.3 (C)
C_Rmp_Rnd_Sw_p2_C: J30.2, SW11.2 (B)
C_Rnd_C: J30.3, SW11.1 (A)
C_Rng_Sw_p1_C: J29.3, SW10.1 (A)
C_Rng_Sw_p3_C: J29.2, SW10.3 (C)
C_Sin_C: J30.6, SW12.3 (C)
C_Sin_Tri_Sw_p2_C: J30.7, SW12.2 (B)
C_Tri_C: J30.8, R47.1, R50.1, SW10.2 (B), SW12.1 (A)
C_VOct_Trim_p3_C: J29.7, RV12.3
C_VOct_Trim_p12_C: J29.8, RV12.1, RV12.2
GND: J54.2, J54.3, J54.4, J54.5, R12.1, R14.2, R15.2, R29.1, R31.2, R32.2, R46.1, R48.2, R49.2, RV1.1, RV5.1, RV9.1
unnamed: D1.1 (K), Q1.1 (C)
unnamed: D2.2 (A), Q2.1 (C)
unnamed: D3.1 (K), Q3.1 (C)
unnamed: D4.2 (A), Q4.1 (C)
unnamed: D5.1 (K), Q5.1 (C)
unnamed: D6.2 (A), Q6.1 (C)
unnamed: Q1.2 (B), R13.2
unnamed: Q1.3 (E), R14.1
unnamed: Q2.2 (B), R16.2
unnamed: Q2.3 (E), R15.1
unnamed: Q3.2 (B), R30.2
unnamed: Q3.3 (E), R31.1
unnamed: Q4.2 (B), R33.2
unnamed: Q4.3 (E), R32.1
unnamed: Q5.2 (B), R47.2
unnamed: Q5.3 (E), R48.1
unnamed: Q6.2 (B), R50.2
unnamed: Q6.3 (E), R49.1
unnamed: R7.2, RV2.3
unnamed: R9.1, RV3.3
unnamed: R11.1, RV2.1
unnamed: R12.2, RV3.1
unnamed: R24.2, RV6.3
unnamed: R26.1, RV7.3
unnamed: R28.1, RV6.1
unnamed: R29.2, RV7.1
unnamed: R41.2, RV10.3
unnamed: R43.1, RV11.3
unnamed: R45.1, RV10.1
unnamed: R46.2, RV11.1

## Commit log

2025-04-26 Created Panel project
    [DMH_VCLFO_PANEL.kicad_pcb, DMH_VCLFO_PANEL.kicad_sch]
2025-04-26 V1 one the panel ready
    [DMH_VCLFO_PANEL.kicad_pcb, DMH_VCLFO_PANEL.kicad_sch]
2025-04-26 V2 panel ready
    - Removed attenuverter
    - Re-added saw output
    - Added sync input
    - Added PLL switch
    - Added unipolar switch
    [DMH_VCLFO_PANEL.kicad_pcb, DMH_VCLFO_PANEL.kicad_sch]
2025-04-28 Starting redesign of panel
    [DMH_VCLFO_PANEL.kicad_pcb, DMH_VCLFO_PANEL.kicad_sch]
2025-04-29 Finished panel v3
    Grouped all outputs at the bottom of the module to avoid cables getting in the way of the knobs
    [DMH_VCLFO_PANEL.kicad_pcb]
2025-10-06 Improved ergonomics
    [DMH_VCLFO_PANEL.kicad_pcb, DMH_VCLFO_PANEL.kicad_sch]
2025-10-20 Replaced PLL with Range
    [DMH_VCLFO_PANEL.kicad_pcb, DMH_VCLFO_PANEL.kicad_sch]
2025-10-20 Added yellow LED to Panel
    [DMH_VCLFO_PANEL.kicad_pcb, DMH_VCLFO_PANEL.kicad_sch]
2025-11-23 Created PCB 1 project
    [Core_Circuit.kicad_sch, DMH_VCLFO_PCB_1.kicad_pcb, DMH_VCLFO_PCB_1.kicad_sch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]
2025-11-26 schematic design in progress
    [Core_Circuit.kicad_sch, DMH_VCLFO_PCB_1.kicad_sch, Inputs_and_Outputs.kicad_sch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]
2025-11-30 Completed basic core circuit schematic
    ... escept for polarization switch
    [Core_Circuit.kicad_sch]
2025-11-30 Ready for breadboarding
    [Core_Circuit.kicad_sch, DMH_VCLFO_PCB_1.kicad_sch, Inputs_and_Outputs.kicad_sch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]
2025-12-01 Fixed issue with polarity selector
    [Core_Circuit.kicad_sch, Inputs_and_Outputs.kicad_sch, Power.kicad_sch]
2025-12-20 Improved sync input
    [Core_Circuit.kicad_sch]
2025-12-20 Exported preliminary BoM
    [preliminary_bom_vclfo.csv]
2026-01-10 Changed name in panel
    [DMH_VCLFO_PANEL.kicad_pcb]
2026-01-10 Documented breadboard layout
    [Breadboard_Layout.kicad_sch, DMH_VCLFO_PCB_1.kicad_sch]
2026-01-12 Annotations during breabboarding troubleshooting
    [Core_Circuit.kicad_sch]
2026-01-15 Centralized library location
    [Inputs_and_Outputs.kicad_sch]
2026-01-24 Breadboard troubleshooting changes
    [Breadboard_Layout.kicad_sch, Core_Circuit.kicad_sch]
2026-01-25 Added super fast range option
    [Core_Circuit.kicad_sch, DMH_VCLFO_PCB_1.kicad_sch, Inputs_and_Outputs.kicad_sch]
2026-01-25 Updated fonts on panel
    [DMH_VCLFO_PANEL.kicad_pcb]
2026-01-29 Preparing schematic for new core circuit
    [Breadboard_Layout.kicad_sch, Core_Circuit.kicad_sch, DMH_VCLFO_v2_PCB_Main.kicad_pcb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]
2026-01-31 Designed osc core based on slew module
    [Core_Circuit.kicad_sch, Inputs_and_Outputs.kicad_sch]
2026-02-01 Adapted sync reset circuit
    [Core_Circuit.kicad_sch, Sync_A.kicad_sch]
2026-02-01 Adapted saw shaper
    [Core_Circuit.kicad_sch, Ramp_Shaper_A.kicad_sch]
2026-02-04 Replaced sine shaper and adapted random
    [Core_Circuit.kicad_sch, Random_A.kicad_sch, Sine_Shaper_A.kicad_sch]
2026-02-05 Improved inter-PCB connections
    [Core_Circuit.kicad_sch, DMH_VCLFO_v2_PCB_Main.kicad_sch, Inputs_and_Outputs.kicad_sch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]
2026-02-08 Notes from breadboarding
    [Breadboard_Layout.kicad_sch, Core_Circuit.kicad_sch, DMH_VCLFO_v2_PCB_Main.kicad_sch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]
2026-02-10 Modified front panel
    Added V/Oct calib trimpot hole
    Replaced Polarity switch with Bus CV
    Added Fine as normalized function of CV Amt pot
    [DMH_VCLFO_PANEL.kicad_pcb, DMH_VCLFO_PANEL.kicad_sch]
2026-02-11 Sch redesign in progress
    [Core_Circuit.kicad_sch, DMH_VCLFO_PANEL.kicad_pcb, DMH_VCLFO_PANEL.kicad_sch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]
2026-02-12 Redesigned schematic for V/Oct
    And also Bus CV and Fine tune
    [Core_Circuit.kicad_sch, Inputs_and_Outputs.kicad_sch, Power.kicad_sch]
2026-02-13 Rearranged symbols in IO page
    [Inputs_and_Outputs.kicad_sch, Power.kicad_sch]
2026-02-14 Adjustments on breadboard
    [Core_Circuit.kicad_sch, Inputs_and_Outputs.kicad_sch]
2026-02-14 Rearranged IO page
    [Core_Circuit.kicad_sch, Inputs_and_Outputs.kicad_sch]
2026-02-14 Prepared for PCB design
    [DMH_VCLFO_v2_PCB_Main.kicad_sch, Inputs_and_Outputs_A.kicad_sch, Inputs_and_Outputs_B.kicad_sch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]
2026-02-15 Controls PCB comp placement in progress
    [Breadboard_Layout.kicad_sch, Core_Circuit.kicad_sch, DMH_VCLFO_PANEL.kicad_pcb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]
2026-02-16 Controls PCB routing done
    [DMH_VCLFO_v2_PCB_Controls.kicad_pcb, Inputs_and_Outputs_A.kicad_sch, Inputs_and_Outputs_B.kicad_sch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]
2026-02-18 Main PCB comp placement in progress
    [DMH_VCLFO_v2_PCB_Controls.kicad_pcb, DMH_VCLFO_v2_PCB_Main.kicad_pcb, Inputs_and_Outputs_A.kicad_sch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]
2026-02-19 Main PCB placement done
    [DMH_VCLFO_v2_PCB_Main.kicad_pcb, Inputs_and_Outputs_A.kicad_sch, Inputs_and_Outputs_B.kicad_sch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]
2026-02-19 Routing attempt
    [DMH_VCLFO_v2_PCB_Main.kicad_pcb]
2026-02-19 Alternative Main PCB placement ongoing
    [DMH_VCLFO_v2_PCB_Main.kicad_pcb]
2026-02-20 Placement attempt done
    [DMH_VCLFO_v2_PCB_Main.kicad_pcb]
2026-02-20 Routing in progress
    [DMH_VCLFO_v2_PCB_Main.kicad_pcb, Sub_module_A.kicad_sch, Sub_module_B.kicad_sch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]
2026-02-21 Main PCB routing done
    [DMH_VCLFO_v2_PCB_Main.kicad_pcb, Inputs_and_Outputs_A.kicad_sch, Inputs_and_Outputs_B.kicad_sch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]
2026-02-21 Synced Controls PCB with Main
    [Inputs_and_Outputs_A.kicad_sch, Inputs_and_Outputs_B.kicad_sch, Inputs_and_Outputs_C.kicad_sch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]
2026-02-21 Created Submodule project
    [Breadboard_Layout.kicad_sch, Core_Circuit.kicad_sch, DMH_VCLFO_v2_PCB_Submodule.kicad_pcb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]
2026-02-21 Submodule comp placement started
    [DMH_VCLFO_v2_PCB_Submodule.kicad_pcb, Sub_module_A.kicad_sch]
2026-02-21 Submodule com placement done
    [DMH_VCLFO_v2_PCB_Submodule.kicad_pcb, Sub_module_A.kicad_sch]
2026-02-21 Submodule routing done
    [DMH_VCLFO_v2_PCB_Submodule.kicad_pcb]
2026-02-21 Generated Gerbers
    [DMH_VCLFO_PANEL-B_Cu.gbl, DMH_VCLFO_PANEL-B_Mask.gbs, DMH_VCLFO_PANEL-B_Paste.gbp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]
2026-04-05 Reorganized folder contents
    [Breadboard_Layout.kicad_sch, Core_Circuit.kicad_sch, DMH_VCLFO_PCB_1.kicad_pcb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]
2026-04-13 Added project with Single VCLFO schematic
    [DMH_VCLFO_SingleUnit.kicad_pcb, DMH_VCLFO_SingleUnit.kicad_sch, DMH_VCLFO_v2_PCB_Controls.kicad_sch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]
2026-07-29 KiCad 10
